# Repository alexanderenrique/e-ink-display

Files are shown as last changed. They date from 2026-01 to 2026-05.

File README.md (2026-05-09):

# E-Ink Display

A custom ESP32-C3-based e-ink display platform with a modular app system, BLE configuration, OTA updates, and three KiCad PCB variants. Built around the Seeed XIAO ESP32-C3 and a 2.9" tri-color (black/white/red) e-ink panel (e.g. GDEM029C90).

## Licensing

Hardware design files in [`e-ink-PCBs/`](e-ink-PCBs/) are licensed under **CERN-OHL-W-2.0**. Firmware, scripts, config examples, and Markdown documentation are under the **MIT License**. See [`LICENSE`](LICENSE), [`LICENSE-HARDWARE`](LICENSE-HARDWARE), and [`LICENSE-SOFTWARE`](LICENSE-SOFTWARE).

## Open source scope (third-party parts)

This project is shared to meet the [Open Source Hardware Definition](https://www.oshwa.org/definition/) and aligns with the spirit of [OSHWA certification requirements](https://certification.oshwa.org/requirements.html) for distinguishing parts outside the licensor’s control.

**Released under the licenses above (our work):**

- Schematics and PCB layouts in [`e-ink-PCBs/`](e-ink-PCBs/) (native KiCad sources and Gerber exports in each variant folder).
- Firmware in [`e-ink_code/firmware/`](e-ink_code/firmware/), plus tooling in [`e-ink_code/scripts/`](e-ink_code/scripts/) and examples under [`e-ink_code/config/`](e-ink_code/config/).

**Not open-sourced by this repository (standard commercial / third-party parts; use vendor documentation):**

| Item | Role | Public datasheet / info |
|---|---|---|
| Seeed XIAO ESP32-C3 | MCU module (ESP32-C3, crystal, antenna, regulators inside module) | Seeed Wiki and [ESP32-C3 technical reference](https://www.espressif.com/en/products/socs/esp32-c3) |
| GDEM029C90 (or compatible Good Display panel) | E-ink panel + timing/controller as supplied by vendor | Vendor PDF (e.g. Good Display product pages) |
| SHT31 | Temperature / humidity sensor IC or module | [Sensirion SHT31 datasheet](https://www.sensirion.com/) |
| FQP27P06, ZXMP4A16G | Discrete MOSFETs | [ON Semi FQP27P06](https://www.onsemi.com/), [Diodes ZXMP4A16G](https://www.diodes.com/) |
| MCP7940N (RTC variant only) | I2C real-time clock | [Microchip MCP7940N](http://ww1.microchip.com/downloads/en/DeviceDoc/20005010F.pdf) |

Optional firmware features (e.g. the **shelf** app) may call HTTP APIs or a companion script (`bin_lookup_server.py`); the hardware and core firmware remain usable without those services.

## Project structure

```
e-ink-display/
├── e-ink-PCBs/                 # KiCad 9 hardware + Gerbers
│   ├── SMD/                    # “SMD” layout variant
│   ├── Throughole-Basic/       # Through-hole, base design
│   ├── Throughole-RTC/         # Through-hole + MCP7940N RTC (+ optional SD header in sch)
│   └── bom/                    # CSV BOM summaries (regenerate from KiCad after edits)
├── e-ink_code/                 # Firmware and scripts (PlatformIO)
│   ├── firmware/               # ESP32-C3 source, core/, apps/, main.cpp
│   ├── scripts/               # OTA, flash, BLE utilities
│   ├── config/examples/       # Device JSON examples
│   ├── platformio.ini
│   └── requirements.txt       # Python deps for helper scripts
├── docs/
│   └── images/                # Add board photos or renders here (recommended for makers)
├── LICENSE, LICENSE-HARDWARE, LICENSE-SOFTWARE, README.md
```

## Hardware

### Components

| Component | Description |
|---|---|
| Seeed XIAO ESP32-C3 | Microcontroller with WiFi and BLE |
| GDEM029C90 | 2.9" 128×296 tri-color e-ink display (black/white/red) |
| SHT31 | I2C temperature and humidity sensor |
| FQP27P06 (and variants may add ZXMP4A16G) | P-channel MOSFETs for power switching |
| 100 µF capacitor | Bulk decoupling (where present in schematic) |
| Resistors | Voltage divider (47 kΩ / 68 kΩ), pull-ups, etc. (see BOM CSVs) |
| Battery connector | LiPo / battery input |
| Through-hole RTC add-ons (Throughole-RTC only) | MCP7940N, 32.768 kHz crystal, load caps; optional SD header in schematic |

### Pin mapping (ESP32-C3)

| Pin | Function |
|-----|---|
| GPIO 3 | SPI SCK (e-ink) |
| GPIO 4 | SPI MOSI (e-ink) |
| GPIO 7 | e-ink CS |
| GPIO 6 | e-ink DC |
| GPIO 5 | e-ink RST |
| GPIO 21 | e-ink BUSY |
| GPIO 9 | I2C SDA (SHT31) |
| GPIO 10 | I2C SCL (SHT31) |
| GPIO 2 | Battery ADC (voltage divider) |
| GPIO 8 | Display + sensor power MOSFET gate |
| GPIO 20 | Battery divider sense enable (`V_SWITCH`) |

### PCB variants

| Directory | Description |
|---|---|
| [`e-ink-PCBs/SMD/`](e-ink-PCBs/SMD/) | Single main FQP27P06 switch; mixed THT footprints on some passives as in schematic |
| [`e-ink-PCBs/Throughole-Basic/`](e-ink-PCBs/Throughole-Basic/) | Through-hole friendly; includes ZXMP4A16G + FQP27P06 in schematic |
| [`e-ink-PCBs/Throughole-RTC/`](e-ink-PCBs/Throughole-RTC/) | Basic topology + MCP7940N RTC, crystal, optional `J6` SD block |

Each folder contains `.kicad_pro`, `.kicad_sch`, `.kicad_pcb`, drill files, and `*.gbr` / `*.gbrjob` fab outputs. **Preferred source for modification is KiCad**, not Gerbers alone.

### Replication: BOM and assembly

1. Open the variant you are building and use **Tools → Generate Bill of Materials** in KiCad to export a fresh CSV when anything changes.
2. Human-readable summaries for each variant live in [`e-ink-PCBs/bom/`](e-ink-PCBs/bom/) — see [`e-ink-PCBs/bom/README.md`](e-ink-PCBs/bom/README.md).
3. Order PCBs using the `e-ink_PCB-job.gbrjob` or individual Gerbers in that variant’s folder.
4. Solder power, MCU module, and display connector before first power-on; double-check battery polarity and MOSFET orientation against the silkscreen.
5. **First firmware:** flash over USB with PlatformIO (see **Build and flash** below) or keep a personal `e-ink_code/FLASH_INSTRUCTIONS.md` locally (that filename is gitignored).
6. **Photos / renders:** add PNGs under [`docs/images/`](docs/images/) (e.g. bare PCB, populated board, enclosure) so others can verify the build.

## Firmware

### Architecture

The firmware uses a plugin-based app system. Core managers handle hardware (WiFi, display, power, OTA, BLE) and are injected into apps via dependency injection. Each app implements the `AppInterface` and is registered with the `AppManager`, which coordinates lifecycle and configuration.

```
Main  -->  AppManager  -->  [Fun | Sensor | Shelf | Messages]
                |
           Core Managers
       (WiFi, Display, Power, OTA, BLE)
```

### Apps

| App | Description |
|-----|---|
| **fun** | Cycles through cat facts, earthquake data, ISS location, useless facts, and local room temperature/humidity. Rotates display mode across deep sleep cycles. |
| **sensor** | Reads temperature and humidity from the SHT31 sensor, displays on screen, and optionally posts data to a Nemo API endpoint. Supports Celsius/Fahrenheit. |
| **shelf** | Queries a bin lookup server to display shelf/bin owner information. Designed for lab inventory labeling. |
| **messages** | Displays a configurable list of up to 10 messages, cycling through them on each wake. |

### BLE configuration

On cold boot (power-on reset), the device advertises via BLE for up to 3 minutes. A BLE central (phone app, script, etc.) can connect and send a JSON configuration including WiFi credentials, app selection, and app-specific settings. The configuration is stored in NVS (non-volatile storage) and persists across deep sleep and reboots.

### Power management

- Battery voltage is read through a 47k/68k resistor divider on GPIO 2.
- Deep sleep is used between display refreshes (configurable per app).
- When battery drops below 5%, the device shows a low-battery message and enters a periodic wake-check sleep (every 5 minutes). Normal operation resumes at 15%.

### OTA updates

The firmware supports HTTPS OTA updates. A deploy script builds the firmware, generates a manifest (version + SHA256), and uploads it to a remote server. Devices check for updates and apply them over WiFi.

### Build environments

Each app has its own PlatformIO build environment that only compiles the code for that specific app:

| Environment | App | Build flag |
|---|-----|---|
| `seeed_xiao_esp32c3` | All apps | (none) |
| `seeed_xiao_fun` | Fun | `-DAPP_FUN` |
| `seeed_xiao_sensor` | Sensor | `-DAPP_SENSOR` |
| `seeed_xiao_shelf` | Shelf | `-DAPP_SHELF` |
| `seeed_xiao_messages` | Messages | `-DAPP_MESSAGES` |

### Dependencies

Managed by PlatformIO (`lib_deps` in `platformio.ini`):

- [GxEPD2](https://github.com/ZinggJM/GxEPD2) — E-ink display driver
- [ArduinoJson](https://github.com/bblanchon/ArduinoJson) ^6.21.3 — JSON parsing
- [Adafruit SHT31 Library](https://github.com/adafruit/Adafruit_SHT31) ^2.2.2 — Temperature/humidity sensor
- [Adafruit Unified Sensor](https://github.com/adafruit/Adafruit_Sensor) ^1.1.9 — Sensor abstraction
- [NimBLE-Arduino](https://github.com/h2zero/NimBLE-Arduino) ^1.4.1 — BLE stack

## Scripts

Located in `e-ink_code/scripts/`:

| Script | Description |
|---|---|
| `deploy_ota.sh` | Build firmware, create manifest, and SCP to OTA server |
| `flash_firmware.sh` | Flash firmware to ESP32-C3 via USB using esptool |
| `bin_lookup_server.py` | Python HTTP server that proxies NEMO API bin/user data for the shelf app |
| `scan_ble.py` | BLE scanner utility to discover and inspect nearby devices |
| `post_build.py` | Copies built firmware binary to `ota/` directory |
| `make_manifest.py` | Generates `manifest.json` with version and SHA256 hash |

## OSHWA certification (administrative next steps)

After this repository reflects the licenses and documentation above, **certification itself is completed on OSHWA’s site**, not in git:

1. Review [Certification requirements](https://certification.oshwa.org/requirements.html) and the [Open Source Hardware checklist](https://www.oshwa.org/resources/open-source-hardware-checklist).
2. Complete the **Certification Mark License Agreement** and submit documentation links for each hardware version you certify.
3. **Register each unique product** that will carry the certification mark, and follow OSHWA’s **mark usage guidelines** (do not imply endorsement by Seeed, Sensirion, Microchip, OSHWA, etc., beyond factual compatibility).
4. Plan for **annual renewal** emails from OSHWA to reaffirm compliance.

Silkscreen and marketing should use only trademarks you are entitled to; third-party logos on the PCB must be cleared separately from this project’s open-license grants.

## Getting started

### Prerequisites

- [PlatformIO](https://platformio.org/) (CLI or IDE plugin)
- [KiCad](https://www.kicad.org/) 9+ (matches current `.kicad_*` schema)
- Python 3 (for utility scripts)

### Build and flash

```bash
cd e-ink_code

# Build a specific app
pio run -e seeed_xiao_sensor

# Upload via USB
pio run -e seeed_xiao_sensor --target upload

# Monitor serial output
pio device monitor
```

### Deploy OTA update

```bash
cd e-ink_code
./scripts/deploy_ota.sh sensor
```

### Run the bin lookup server (shelf app)

```bash
cd e-ink_code
pip install requests python-dotenv
# Set NEMO_API_KEY in a .env file
python scripts/bin_lookup_server.py
```

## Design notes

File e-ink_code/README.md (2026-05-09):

# E-Ink firmware (`e-ink_code`)

PlatformIO firmware for the Seeed **XIAO ESP32-C3** driving a **GDEM029C90-class** 2.9" three-color e-paper display (B/W/R). Pinout and board documentation live in the [repository root README](../README.md).

## Prerequisites

- [PlatformIO](https://platformio.org/) (CLI or IDE)
- Python 3 (OTA helper scripts under `scripts/`)

PlatformIO uses **`src_dir = firmware`** — all application code is under `firmware/`, not `src/`.

## Quick start

```bash
cd e-ink_code

# Build one app (recommended for smaller binaries)
pio run -e seeed_xiao_sensor

pio run -e seeed_xiao_sensor --target upload
pio device monitor
```

## Build environments

| Environment | `APP_*` flag | Typical use |
|---|---|---|
| `seeed_xiao_esp32c3` | *(none — all apps linked)* | Development / multi-app image |
| `seeed_xiao_fun` | `APP_FUN` | Fun / info modules only |
| `seeed_xiao_sensor` | `APP_SENSOR` | Room sensor + optional Nemo |
| `seeed_xiao_shelf` | `APP_SHELF` | Shelf / bin label |
| `seeed_xiao_messages` | `APP_MESSAGES` | Static message list |

Defined in [`platformio.ini`](platformio.ini).

## Source layout

```
e-ink_code/
├── firmware/
│   ├── main.cpp              # Boot, NVS config, app wiring, BLE gating
│   ├── app_manager/          # App selection + JSON configure
│   ├── core/
│   │   ├── hardware_config.h # Pins, battery, OTA URL macros (edit for your server)
│   │   ├── bluetooth/        # Cold-start BLE setup
│   │   ├── display/, wifi/, power/, ota/
│   └── apps/
│       ├── fun/              # Rotating “modules” (sensor + HTTP APIs)
│       ├── sensor/           # SHT31 + optional Nemo posting
│       ├── shelf/            # HTTP client to bin-lookup style server
│       └── messages/         # Up to 10 configured strings
├── scripts/                  # deploy_ota.sh, manifest, flash helpers
├── config/examples/          # JSON shape examples for BLE / tools
├── include/                  # Optional shared headers (e.g. reference CA PEM)
├── partitions.csv
├── version.txt               # Keep in sync with FIRMWARE_VERSION for OTA
└── platformio.ini
```

## Apps (summary)

| App | Role |
|-----|---|
| **fun** | Local SHT31 “room” tile plus optional WiFi feeds (earthquake, cat facts, ISS, trivia); cycles modes; **only this app wires HTTPS OTA** today (`handleOTA()`). |
| **sensor** | Temperature/humidity display; optional Nemo/API posting per `config`. |
| **shelf** | Fetches label text from a configurable HTTP server (`serverHost` / `serverPort` / `binId`). |
| **messages** | Shows a fixed list of lines from config. |

Active app and `config` object come from JSON (BLE-stored NVS or the built-in test default in `main.cpp`). See [`config/examples/README.md`](config/examples/README.md).

## Pins (authoritative: `firmware/core/hardware_config.h`)

| Signal | GPIO |
|---|---|
| SPI SCK | 3 |
| SPI MOSI | 4 |
| E-ink CS | 7 |
| E-ink DC | 6 |
| E-ink RST | 5 |
| E-ink BUSY | 21 |
| I2C SDA / SCL (SHT31) | 9 / 10 |
| Battery ADC | 2 |
| Display + sensor power MOSFET gate | 8 |
| Divider enable `V_SWITCH` | 20 |

## Bluetooth setup (cold start)

- Implemented in [`firmware/core/bluetooth/cold_start_ble.cpp`](firmware/core/bluetooth/cold_start_ble.cpp).
- BLE runs only on a true cold start (not deep-sleep timer wake); advertising window **15 s** (`COLD_START_BLE_WINDOW_SECONDS` in [`cold_start_ble.h`](firmware/core/bluetooth/cold_start_ble.h)).
- WiFi is turned off while BLE is active (ESP32-C3 coexistence).
- After JSON config is written to the TX characteristic, preferences store `configJson` and set a one-shot **`skipBLE`** so the next reboot applies settings without re-entering BLE.

## Power and deep sleep

- Apps call `PowerManager::enterDeepSleep()` after a refresh cycle.
- Set **`DISABLE_DEEP_SLEEP_FOR_TESTING`** to `1` in [`hardware_config.h`](firmware/core/hardware_config.h) to replace deep sleep with a long `delay()` (USB serial stays usable).

## OTA updates

- **Fun** app: `handleOTA()` passes `OTA_VERSION_CHECK_URL`, `ROOT_CA_CERT`, `OTA_PASSWORD`, and `FIRMWARE_VERSION` from [`hardware_config.h`](firmware/core/hardware_config.h) into `OTAManager`.
- Manifest over HTTPS must be JSON with at least **`version`** and **`url`** (firmware `.bin`). Version must be newer than the device (`x.y.z` compared in [`ota_manager.cpp`](firmware/core/ota/ota_manager.cpp)).
- `scripts/make_manifest.py` also writes **`sha256`** for your deployment records; the current firmware path does not verify that hash on device.
- Dual OTA partitions: [`partitions.csv`](partitions.csv). Deploy flow: `scripts/deploy_ota.sh` (see script for host/path variables).

## Scripts

| Script | Purpose |
|---|---|
| `scripts/deploy_ota.sh` | Build, post-build, manifest, SCP to server |
| `scripts/make_manifest.py` | `ota/manifest.json` from `version.txt` + `ota/firmware.bin` |
| `scripts/post_build.py` | Copy firmware binary into `ota/` |
| `scripts/flash_firmware.sh` | USB flash helper |

## Versioning

1. Bump [`version.txt`](version.txt).
2. Match **`FIRMWARE_VERSION`** in [`firmware/core/hardware_config.h`](firmware/core/hardware_config.h).

## License

Firmware, scripts, config examples, and Markdown here are **MIT**. See [`LICENSE-SOFTWARE`](../LICENSE-SOFTWARE) and [`LICENSE`](../LICENSE). Hardware CAD is **CERN-OHL-W-2.0** under [`../e-ink-PCBs/`](../e-ink-PCBs/).

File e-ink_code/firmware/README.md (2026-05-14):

# E-Ink Display Firmware Architecture

This document describes the modular firmware architecture for the ESP32-C3 e-ink display system. The firmware is designed around a plugin-based app system where multiple applications can run on the same hardware, each with its own functionality and configuration.

## Table of Contents

- [Architecture Overview](#architecture-overview)
- [Core Components](#core-components)
- [App System](#app-system)
- [Available Apps](#available-apps)
- [JSON Configuration](#json-configuration)
- [Testing with JSON](#testing-with-json)
- [Adding New Apps](#adding-new-apps)
- [Build and Deployment](#build-and-deployment)

## Architecture Overview

The firmware follows a layered architecture with clear separation of concerns:

```
┌─────────────────────────────────────────┐
│           Main Application              │
│         (main.cpp)                      │
└─────────────────┬───────────────────────┘
                  │
┌─────────────────▼───────────────────────┐
│          App Manager                    │
│    (app_manager/app_manager.*)         │
│  - Manages app lifecycle                │
│  - Handles app switching                │
│  - Parses JSON configuration            │
└─────┬───────────┬───────────┬───────────┘
      │           │           │
┌─────▼─────┐ ┌──▼───┐ ┌─────▼─────┐
│  Fun App  │ │Sensor│ │ Shelf App │
│           │ │ App  │ │           │
└───────────┘ └──────┘ └───────────┘
      │           │           │
      └───────────┴───────────┘
                  │
      ┌───────────┴───────────┐
      │   Core Managers       │
      ├───────────────────────┤
      │  WiFiManager           │
      │  DisplayManager        │
      │  PowerManager          │
      │  OTAManager            │
      └───────────────────────┘
```

### Key Design Principles

1. **Dependency Injection**: Core managers are injected into apps through the `AppInterface`, allowing apps to access hardware and services without tight coupling.

2. **Plugin Architecture**: Apps implement the `AppInterface` and are registered with the `AppManager`. The active app can be switched at runtime or via JSON configuration.

3. **Separation of Concerns**: Each app is self-contained with its own:
   - `app.h/cpp` - Main app logic
   - `fetch.h/cpp` - Data fetching logic
   - `render.h/cpp` - Display rendering logic
   - `config.h` - App-specific configuration

4. **Resource Management**: Apps are responsible for managing their own resources (WiFi connections, display updates, sleep cycles) with guidance from core managers.

## Core Components

### Core Managers

Located in `firmware/core/`, these managers provide hardware abstraction and shared services:

#### WiFiManager (`core/wifi/`)
- Manages WiFi connections
- Handles connection/disconnection lifecycle
- Provides connection status checking

#### DisplayManager (`core/display/`)
- Manages e-ink display initialization and updates
- Provides rendering helpers (text wrapping, battery display)
- Handles SPI initialization and cleanup
- Supports multiple display modes (default, earthquake, ISS data)

#### PowerManager (`core/power/`)
- Battery voltage monitoring and percentage calculation
- Deep sleep management
- Wake-up reason detection
- Power optimization utilities

#### OTAManager (`core/ota/`)
- Over-the-air firmware updates
- Version checking against remote server
- Secure update handling with certificate validation

### Hardware Configuration

All hardware pin definitions and constants are centralized in `firmware/core/hardware_config.h`:

- SPI pins (SCK, MOSI, MISO, CS, DC, RST, BUSY)
- I2C pins (SDA, SCL)
- Power management pins (V_ADC, V_SWITCH)
- Battery voltage divider constants
- WiFi credentials
- OTA server configuration

## App System

### AppInterface

All apps must implement the `AppInterface` base class (`app_manager/app_interface.h`):

```cpp
class AppInterface {
public:
    virtual bool begin() = 0;              // Initialize app
    virtual void loop() = 0;               // Main app loop
    virtual void end() = 0;                // Cleanup on app switch
    virtual const char* getName() = 0;     // Return app name
    virtual bool configure(const JsonObject& config); // Optional config
    
    // Dependencies (injected by AppManager)
    void setWiFiManager(WiFiManager* wifi);
    void setDisplayManager(DisplayManager* display);
    void setPowerManager(PowerManager* power);
    void setOTAManager(OTAManager* ota);
};
```

### AppManager

The `AppManager` (`app_manager/app_manager.*`) coordinates the app system:

**Key Responsibilities:**
- Register apps with unique names
- Set active app (by name or index)
- Parse JSON configuration and apply it
- Inject core manager dependencies into apps
- Manage app lifecycle (begin/loop/end)
- Provide app query methods

**Key Methods:**
- `registerApp(AppInterface* app, const char* name)` - Register an app
- `setActiveApp(const char* name)` - Switch to an app by name
- `configureFromJson(const char* jsonString)` - Configure from JSON
- `begin()` - Start the active app
- `loop()` - Run the active app's loop

## Available Apps

### Fun App (`apps/fun/`)

Displays rotating content including:
- Room temperature and humidity (from SHT31 sensor, no WiFi needed)
- Earthquake data (requires WiFi)
- Cat facts (requires WiFi)
- ISS location data (requires WiFi)
- Useless facts (requires WiFi)
- Optional one-off slides pushed from the aggregator (**special messages**; requires WiFi, device UUID, and server-side queue — see **`apis.special_messages`** below)

**Display Modes:** Cycles through 5 modes (0-4), persisting across deep sleep using `RTC_DATA_ATTR`.

**WiFi / aggregator usage:** The ESP only calls the fun HTTP endpoints for modes that are enabled in configuration (see **`config.apis`** below). The server does not enforce per-mode policy; it responds to whatever the client requests once `X-Fun-Key` matches (if the server is configured with `FUN_API_KEY`).

### Fun app `apis` flags (BLE / stored JSON)

When the fun app is configured (including data loaded from NVS after provisioning over BLE), optional `config.apis` booleans turn each **display mode** on or off:

| Key | Mode | Content |
|-----|---|---|
| `room_data` | 0 | Room temp/humidity (and WiFi RSSI when connected) |
| `earthquake` | 1 | Earthquake slide (WiFi) |
| `cat_facts` | 2 | Cat facts — one `GET /v1/fun/screen?m=2` per wake (WiFi), unless `all_new_facts` |
| `iss` | 3 | ISS slide (WiFi) |
| `useless_facts` | 4 | Useless facts — one `GET /v1/fun/screen?m=4` per wake (WiFi); ignored when `all_new_facts` is on |
| `all_new_facts` | (uses mode 2) | When `true`, mode 2 calls `GET /v1/fun/facts/mixed?count=1` so the device shows a random slide from **any** non-empty `data/*_facts.json` pool on the server; mode 4 is skipped so cat vs useless toggles do not duplicate a second facts slot |
| `special_messages` | (WiFi modes 1–4) | When `true` (default), each wake in an online WiFi mode first calls `GET /v1/fun/special` using the stored device UUID (`X-Device-Id`). If the server returns a slide, that slide is shown **instead of** the normal earthquake/cat/ISS/mixed/useless slide for this cycle (the message is dequeued server-side). If the server responds with no body (`204`), the firmware continues with the usual mode fetch |

Fact text is always fetched live over WiFi for those modes (no NVS queue). The server still exposes `GET /v1/fun/facts/batch` for other clients; the fun app firmware no longer uses it.

**Defaults:** If there is no `apis` object (e.g. `{"app":"fun","config":{}}` in [`main.cpp`](main.cpp) when nothing is stored from BLE), **all flags default to on** in [`apps/fun/app.h`](apps/fun/app.h). To limit network use, set `apis` explicitly, for example:

```json
{
  "app": "fun",
  "config": {
    "refreshInterval": 2,
    "apis": {
      "room_data": true,
      "cat_facts": true,
      "iss": true,
      "earthquake": false,
      "useless_facts": false,
      "all_new_facts": false,
      "special_messages": true
    }
  }
}
```

BLE provisioning stores a top-level `apis` object that [`main.cpp`](main.cpp) merges into `config` when building the app-manager JSON.

**Device identity (aggregator / special messages):** In top-level provisioning JSON you can send a human-readable label (any of `displayName`, `deviceFriendlyName`, or `friendly_name`) which is persisted as `deviceFriendlyName` in Preferences and sent on each aggregator request as the `X-Device-Name` header. Optionally include `deviceId` / `device_id` (UUID) if you mint the ID in the provisioning app (**phone-mint**); otherwise NVS keeps `deviceId` empty until the firmware calls `POST /v1/devices/register` once (server-mint UUID), then repeats that id as `X-Device-Id` on later calls. To queue a one-off slide for a given UUID (or a named group), use the server admin API documented in [server README — Special messages](../server/README.md#special-messages-targeted-slides).

**Special messages — did the server / device accept it?**

- **Enqueue accepted (admin):** A successful `POST /v1/admin/special` returns HTTP **200** with JSON like `{"ok":true,"enqueued_for":["…uuid…"],"unknown_groups":[]}` — **`enqueued_for`** is the definitive list of device UUIDs that received a queued copy. If **`ok`** is **`false`**, read **`error`**; **`unknown_groups`** means one or more **`group_ids`** were not defined in the on-disk store yet (define them with **`groups`** in the same request, or persist them beforehand — see below).
- **Still waiting vs. consumed (device):** There is **no separate HTTP endpoint** for delivery receipts. Pending items live in the server file **`FUN_SPECIAL_STORE`** (default `data/special_messages.json`; often **`/var/lib/fun-aggregator/special_messages.json`** on a Pi — see server README). It is structured as **`queues`** (per-device UUID FIFO arrays) and **`groups`** (named lists of UUIDs). After enqueue, **`queues.<device-uuid>`** holds pending slide objects until the firmware’s next successful **`GET /v1/fun/special`**; that POP **removes** the head entry and returns the slide, so seeing the slide on the ink display is the strongest proof the device consumed it. Inspect the JSON on the Pi (or `jq '.queues."YOUR-DEVICE-UUID"' /path/to/special_messages.json`) to see what is **still queued**; **`204`** on **`/v1/fun/special`** means nothing left for that UUID. Firmware serial output logs HTTP/JSON failures for **`/v1/fun/special`** (see `[FunFetch] Special slide …`); a clean fetch does not spam success logs — use the screen or the store file.

**Special messages — grouping UUIDs**

Named groups are **server-side strings** pointing at **lists of device UUID strings** in **`FUN_SPECIAL_STORE.groups`**. Typical workflow from your laptop against the public API (same pattern on the Pi with `http://127.0.0.1:8081`):

1. **Define or update a group** and **enqueue in one request** — the **`groups`** object is merged **before** **`group_ids`** is resolved for that POST:

```bash
curl -sS -X POST 'https://YOUR-HOST/v1/admin/special' \
  -H 'Content-Type: application/json' \
  -H 'X-Fun-Admin-Key: YOUR_ADMIN_SECRET' \
  -d '{"text":"Hi everyone","group_ids":["book_club"],"groups":{"book_club":["uuid-1-here","uuid-2-here"]}}'
```

2. **Later posts** can reference **`group_ids":["book_club"]`** alone if that group already exists in the JSON file — or supply **`groups`** again to replace the membership (the server **replaces** the list for that name when **`groups`** is present; an **empty array** **`"groups":{"book_club":[]}`** **removes** that group mapping).

You can combine **`device_ids`** and **`group_ids`** in the same body; duplicates are merged. Full curl examples and env vars (**`FUN_ADMIN_API_KEY`**, **`FUN_SPECIAL_STORE`**) are in [server README — Special messages](../server/README.md#special-messages-targeted-slides).

**Dependencies:** SHT31 sensor (I2C), WiFi for API calls

### Sensor App (`apps/sensor/`)

Dedicated sensor reading and display app.

**Status:** Implementation in progress

### Shelf App (`apps/shelf/`)

Shelf/bookshelf display app.

**Status:** Implementation in progress

## JSON Configuration

The firmware supports configuration via JSON strings. This allows for:
- Runtime app selection
- App-specific configuration
- Testing different configurations without recompiling
- Future remote configuration support

### JSON Format

The JSON configuration follows this structure:

```json
{
  "app": "app_name",
  "config": {
    // App-specific configuration (optional)
  }
}
```

**Required Fields:**
- `app` (string): The name of the app to activate. Must match a registered app name.

**Optional Fields:**
- `config` (object): App-specific configuration object. Each app can define its own configuration schema.

### JSON Parsing

The `AppManager::configureFromJson()` method:
1. Parses the JSON string using ArduinoJson
2. Validates the `app` field exists
3. Finds the registered app matching the name
4. Switches to that app (calling `end()` on the previous app if switching)
5. Calls the app's `configure()` method with the `config` object (if provided)
6. Returns `true` on success, `false` on failure

**Error Handling:**
- Invalid JSON: Returns `false`, logs parse error
- Missing `app` field: Returns `false`, logs error
- Unknown app name: Returns `false`, logs error
- Configuration failure: Returns `false` if app's `configure()` returns `false`

## Testing with JSON

### Method 1: Hardcoded Test Configuration

Edit `firmware/main.cpp` and modify the `TEST_CONFIG_JSON` constant:

```cpp
// Example: Switch to sensor app
const char* TEST_CONFIG_JSON = 
    "{\"app\": \"sensor\", \"config\": {}}";

// Example: Switch to shelf app
const char* TEST_CONFIG_JSON = 
    "{\"app\": \"shelf\", \"config\": {}}";

// Example: Fun app with empty config (default)
const char* TEST_CONFIG_JSON = 
    "{\"app\": \"fun\", \"config\": {}}";
```

The configuration is applied in `setup()`:

```cpp
if (appManager.configureFromJson(TEST_CONFIG_JSON)) {
    Serial.println("[Main] Configuration loaded successfully");
} else {
    Serial.println("[Main] Configuration failed, using default");
    appManager.setActiveApp("fun"); // Fallback
}
```

### Method 2: Serial Input (Future Enhancement)

For runtime configuration, you could add Serial input parsing:

```cpp
void loop() {
    if (Serial.available()) {
        String jsonInput = Serial.readString();
        if (appManager.configureFromJson(jsonInput.c_str())) {
            Serial.println("Configuration updated!");
            appManager.begin(); // Restart with new config
        }
    }
    appManager.loop();
}
```

### JSON Examples

#### Basic App Selection

```json
{
  "app": "fun"
}
```

#### App Selection with Empty Config

```json
{
  "app": "sensor",
  "config": {}
}
```

#### App Selection with Configuration (Example)

```json
{
  "app": "fun",
  "config": {
    "displayMode": 2,
    "updateInterval": 300,
    "enableWiFi": true
  }
}
```

**Note:** The actual configuration schema depends on each app's `configure()` implementation. Currently, most apps use the default `configure()` which accepts any config and returns `true`.

### Testing Workflow

1. **Edit Configuration**: Modify `TEST_CONFIG_JSON` in `main.cpp`
2. **Build**: Compile the firmware with PlatformIO
3. **Upload**: Flash to device
4. **Monitor**: Check Serial output for configuration status
5. **Verify**: Confirm the correct app is running

### Serial Output

When configuration is applied, you'll see:

```
[AppManager] Registered app: fun
[AppManager] Registered app: sensor
[AppManager] Registered app: shelf
[AppManager] Setting active app to: fun
[AppManager] App configured successfully
[Main] Configuration loaded successfully
[FunApp] Starting Fun App
```

If configuration fails:

```
[AppManager] JSON parse error: InvalidInput
[Main] Configuration failed, using default
[AppManager] Switched to app: fun
```

## Adding New Apps

To add a new app to the system:

### 1. Create App Directory Structure

```
firmware/apps/your_app/
├── app.h
├── app.cpp
├── config.h
├── fetch.h      (optional, for data fetching)
├── fetch.cpp    (optional)
├── render.h     (optional, for display rendering)
└── render.cpp   (optional)
```

### 2. Implement AppInterface

Create your app class inheriting from `AppInterface`:

```cpp
// apps/your_app/app.h
#include "../../app_manager/app_interface.h"

class YourApp : public AppInterface {
public:
    YourApp();
    virtual ~YourApp() {}
    
    bool begin() override;
    void loop() override;
    void end() override;
    const char* getName() override { return "your_app"; }
    
    // Optional: Override configure if you need JSON config
    bool configure(const JsonObject& config) override;
    
private:
    // Your app-specific members
};
```

### 3. Implement Required Methods

```cpp
// apps/your_app/app.cpp
#include "app.h"

bool YourApp::begin() {
    Serial.println("[YourApp] Starting");
    if (_display) {
        _display->begin();
    }
    return true;
}

void YourApp::loop() {
    // Your app logic here
    // Access managers via _wifi, _display, _power, _ota
}

void YourApp::end() {
    Serial.println("[YourApp] Ending");
    // Cleanup resources
}

bool YourApp::configure(const JsonObject& config) {
    // Parse config if needed
    // Return true on success, false on failure
    return true;
}
```

### 4. Register App in main.cpp

```cpp
// Add include
#include "apps/your_app/app.h"

// Create instance
YourApp yourApp;

// Register in setup()
appManager.registerApp(&yourApp, "your_app");
```

### 5. Add JSON Configuration Support (Optional)

If your app needs configuration, implement `configure()`:

```cpp
bool YourApp::configure(const JsonObject& config) {
    if (config.containsKey("someSetting")) {
        _someSetting = config["someSetting"];
    }
    return true;
}
```

Then users can configure it:

```json
{
  "app": "your_app",
  "config": {
    "someSetting": 123
  }
}
```

## Build and Deployment

### Prerequisites

- PlatformIO installed
- ESP32-C3 board support
- Required libraries (see `platformio.ini`)

### Build

```bash
pio run
```

### Upload

```bash
pio run --target upload
```

### Monitor Serial Output

```bash
pio device monitor
```

### OTA Updates

The firmware supports OTA updates via `OTAManager`. Configure:
- `OTA_VERSION_CHECK_URL` in `hardware_config.h`
- `OTA_PASSWORD` in `hardware_config.h`
- `ROOT_CA_CERT` in `hardware_config.h`

Apps can check for updates during their loop:

```cpp
if (_ota && _wifi && _wifi->isConnected()) {
    _ota->handle();
    if (_ota->checkForUpdate()) {
        _ota->performUpdate();
    }
}
```

## File Structure

```
firmware/
├── main.cpp                    # Entry point, app registration
├── core/                       # Core managers
│   ├── hardware_config.h      # Hardware pin definitions
│   ├── wifi/                  # WiFi management
│   ├── display/               # Display management
│   ├── power/                 # Power management
│   └── ota/                   # OTA updates
├── app_manager/               # App system
│   ├── app_interface.h        # Base app interface
│   ├── app_manager.h          # App manager header
│   └── app_manager.cpp        # App manager implementation
└── apps/                      # Application plugins
    ├── fun/                   # Fun app
    ├── sensor/                # Sensor app
    └── shelf/                 # Shelf app
```

## Troubleshooting

### App Not Found Error

- Ensure the app is registered in `main.cpp` with `registerApp()`
- Check that the app name in JSON matches the registration name (case-sensitive)
- Verify the app's `getName()` returns the expected string

### Configuration Not Applied

- Check Serial output for JSON parse errors
- Verify JSON syntax is valid (use a JSON validator)
- Ensure the app's `configure()` method returns `true`
- Check that `config` field is a JSON object, not a string

### App Not Starting

- Verify `begin()` returns `true`
- Check Serial output for initialization errors
- Ensure core managers are properly initialized before app registration
- Verify hardware connections match `hardware_config.h`

## Future Enhancements

Potential improvements to the architecture:

1. **Remote Configuration**: Load JSON config from a web server or MQTT broker
2. **App State Persistence**: Save app state to EEPROM/Flash
3. **Dynamic App Loading**: Load apps from SPIFFS or external storage
4. **Configuration Schema Validation**: Validate JSON against app-defined schemas
5. **App Dependencies**: Support for apps that depend on other apps
6. **Multi-App Mode**: Run multiple apps simultaneously (split screen, cycling)

## License

Firmware in this directory is licensed under the MIT License. See
[`LICENSE-SOFTWARE`](../../LICENSE-SOFTWARE) and the overview in
[`LICENSE`](../../LICENSE).

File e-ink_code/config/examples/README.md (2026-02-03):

# Device config JSON examples

Deploy these (or your variants) to `https://ota.denton.works/config/devices/` so each device can fetch `{name}.json` (e.g. `dillon.json`) or fall back to `default.json`.

All keys are **optional**; firmware uses defaults when a key is missing.

| Key | Type | Default | Description |
|-----|---|---|---|
| `refresh_ms` | number | 300000 | Milliseconds between display cycles (min 10000). |
| `modules` | object | all true | Human-readable toggles. Each key is a module name, value is `true`/`false`. Names: `room`, `meow_fact`, `Earthquakes`, `Iss_location`, `useless_fact`. Cycle order: room → Earthquakes → meow_fact → Iss_location → useless_fact. |
| `messages_url` | string | "" | URL for custom messages endpoint. |
| `messages_key` | string | "" | Optional API key for messages. |
| `key` | string | "" | Arbitrary per-device value. |

To add new config options later: extend the schema in `src_hold/device_config.h`, parse in `device_config.cpp`, and add a getter with a default.

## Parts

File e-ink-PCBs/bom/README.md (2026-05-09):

# Bill of materials

CSV summaries here mirror the KiCad schematics in each PCB variant. **Regenerate
from KiCad** when you change symbols or values so MPNs and references stay
accurate:

1. Open `e-ink_PCB.kicad_sch` in KiCad for the variant you care about.
2. **Tools → Generate Bill of Materials** (pick fields you want, e.g.
   Reference, Value, Footprint, MPN).
3. Export CSV and replace or supplement the files in this directory.

These CSVs intentionally omit power symbols (`#PWR*`) and decorative
schematic-only items.

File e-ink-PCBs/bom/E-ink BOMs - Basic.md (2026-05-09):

# Basic display BOM (no RTC)

| Reference | Value | Suggested MPN / part | Description | Footprint notes | Qty | US$ @ 1 ea | US$ line @ 1 | US$ @ 10 ea | US$ line @ 10 | US$ @ 100 ea | US$ line @ 100 | Notes | Link |
| --- | --- | --- | --- | --- | ---:| ---:| ---:| ---:| ---:| ---:| ---:| --- | --- |
| J2 | e-ink display |  |  |  | 1 | $9.00000 | $9.00000 | $8.00000 | $8.00000 | $8.00000 | $8.00000 | Hard to find the exact one | [AliExpress][j2-link] |
| J1 | Seeed-ESP32 C3 |  | MCU |  | 1 | $4.90000 | $4.90000 | $4.20000 | $4.20000 | $4.20000 | $4.20000 |  |  |
| ANT1 | u.fl Antenna |  | Wifi Antenna |  | 1 | $0.50000 | $0.50000 | $0.50000 | $0.50000 | $0.50000 | $0.50000 |  |  |
| J3 | SHT31 | SHT-31D |  |  | 1 | $2.30000 | $2.30000 | $1.50000 | $1.50000 | $1.00000 | $1.00000 | Many kind of SHT sensors, using SHT-31D, easy to find on amazon |  |
| 47k1 | 47 kΩ | MFR50SFTE52-47K | Throughole, 0.5W, metal film |  | 1 | $0.10000 | $0.10000 | $0.04800 | $0.04800 | $0.03070 | $0.03070 | Top of Voltage Divider |  |
| 68k1 | 68 kΩ | MF0207FTE52-68K | Throughole, 0.5W, metal film |  | 1 | $0.10000 | $0.10000 | $0.05000 | $0.05000 | $0.03280 | $0.03280 | Bottom of Voltage divider |  |
| 1M1 | 1 MΩ | MFR-25FTE52-1M | Throughole, 0.5W, metal film |  | 1 | $0.10000 | $0.10000 | $0.03700 | $0.03700 | $0.02400 | $0.02400 | Pull up for MOSFET; placement 1 of 2 from original qty-2 line. |  |
| 1M2 | 1 MΩ | MFR-25FTE52-1M | Throughole, 0.5W, metal film |  | 1 | $0.10000 | $0.10000 | $0.03700 | $0.03700 | $0.02400 | $0.02400 | Pull up for MOSFET; placement 2 of 2 from original qty-2 line. |  |
| Q1 | P-Type MOSFET | BSP92PH6327XTSA1 | SMD, SOT-223-4 |  | 1 | $0.93000 | $0.93000 | $0.58000 | $0.58000 | $0.37000 | $0.37000 | P-Channel 250 V 260mA (Ta) 1.8W (Ta) Surface Mount PG-SOT223-4; placement 1 of 2 from original qty-2 BOM line. |  |
| Q2 | P-Type MOSFET | BSP92PH6327XTSA1 | SMD, SOT-223-4 |  | 1 | $0.93000 | $0.93000 | $0.58000 | $0.58000 | $0.37000 | $0.37000 | P-Channel 250 V 260mA (Ta) 1.8W (Ta) Surface Mount PG-SOT223-4; placement 2 of 2 from original qty-2 BOM line. |  |
| C1 | 10 µF | FG18X5R1E106MRT06 |  |  | 1 | $0.04500 | $0.04500 | $0.27300 | $0.27300 | $0.18190 | $0.18190 | Power Entry Cap |  |
| C2 | 0.1 µF | K104K15X7RF5TL2 | Throughole, Ceramic |  | 1 | $0.26000 | $0.26000 | $0.14900 | $0.14900 | $0.09480 | $0.09480 | One for each power pin; placement 1 of 2 from original qty-2 line. |  |
| C3 | 0.1 µF | K104K15X7RF5TL2 | Throughole, Ceramic |  | 1 | $0.26000 | $0.26000 | $0.14900 | $0.14900 | $0.09480 | $0.09480 | One for each power pin; placement 2 of 2 from original qty-2 line. |  |
| C4 | 10 pF | K100J15C0GF53L2 | Throughole, Ceramic |  | 1 | $0.24000 | $0.24000 | $0.14000 | $0.14000 | $0.08900 | $0.08900 | For oscillator; placement 1 of 2 from original qty-2 line. |  |
| C5 | 10 pF | K100J15C0GF53L2 | Throughole, Ceramic |  | 1 | $0.24000 | $0.24000 | $0.14000 | $0.14000 | $0.08900 | $0.08900 | For oscillator; placement 2 of 2 from original qty-2 line. |  |
| TOTALS |  |  | BOM cost rollup (all lines summed at each price breakpoint) |  |  |  | **$20.00500** |  | **$16.38300** |  | **$15.10100** | Carried forward from original CSV columns Cost/single/unit ($20.005), Cost/10/unit ($16.383), cost/100/unit ($15.101). |  |

## Rolled-up BOM cost (from sheet)

| Breakpoint | Total (all lines) |
| --- | ---: |
| Buy as ones (matches `Cost_Single_line_total` sum) | $20.00500 |
| Buy at 10-unit pricing | $16.38300 |
| Buy at 100-unit pricing | $15.10100 |

[j2-link]: https://www.aliexpress.us/item/3256808057925649.html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

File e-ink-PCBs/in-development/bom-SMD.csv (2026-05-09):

Reference | Value | Suggested_MPN_or_part | Description | Footprint_notes
J1 | SEED C3 | Seeed Studio XIAO ESP32-C3 | ESP32-C3 module Wi-Fi/BLE | Use official XIAO ESP32-C3; match project footprint Module:XIAO-ESP32C3-SMD_alex
J2 | e-ink-display | GDEM029C90 (or vendor equivalent) | 2.9in 128x296 B/W/R e-paper + flex tail | Install per panel vendor drawing; aligns to 8p 2.54mm header on PCB
J3 | SHT31 | Adafruit 2857 / Sensirion SHT31 breakout or bare IC | Temperature & humidity I2C sensor | Symbol is 4-pin 2.54mm socket
J4 | 100 uF CAP |  | Electrolytic bulk decoupling near supply | Radial 8mm pitch per schematic; verify voltage rating for your battery max
J5 | Batt Conn |  | 2-pin LiPo / battery input | 2.00mm pitch 1x2 socket per footprint
C1 | C_Small_US |  | Ceramic decoupling (populate value per your design—e.g. 100nF) | Disc cap footprint in schematic
R1 | R_Small_US | 47 kΩ ±5% 1/4W | Battery divider top (to GPIO ADC) | Match firmware divider math in software docs
R2 | R_Small_US | 68 kΩ ±5% 1/4W | Battery divider bottom | Pair with R1 for expected ratio
R3 | R_Small_US |  | Pull-up / bias (set value per schematic trace—verify in KiCad) | Axial THT in schematic
Q1 | FQP27P06 | ON Semi FQP27P06 | P-channel power switch | Schematic shows TO-220 footprint; confirm against PCB copper

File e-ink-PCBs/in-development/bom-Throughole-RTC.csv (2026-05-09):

Reference | Value | Suggested_MPN_or_part | Description | Footprint_notes
J1 | SEED C3 | Seeed Studio XIAO ESP32-C3 | ESP32-C3 module | Through-hole XIAO footprint variant
J2 | e-ink-display | GDEM029C90 (or vendor equivalent) | E-paper panel | 8p 2.54mm header
J3 | SHT31 | Adafruit 2857 / SHT31 | I2C sensor | 1x4 2.54mm socket
C2 | C_Small_US |  | RTC crystal load / bypass (value per crystal datasheet)
C3 | C_Small_US |  | RTC crystal load / bypass (value per crystal datasheet)
BT1 | Battery_Cell |  | RTC backup cell (symbolic) | Use non-rechargeable cell appropriate for MCP7940N VBAT per datasheet
R3 | R_Small_US |  | Pull-up or bias (confirm value in schematic)
Q1 | FQP27P06 | ON Semi FQP27P06 | P-channel MOSFET power switch
Q2 | ZXMP4A16G | Diodes Inc. ZXMP4A16G | P-channel MOSFET SOT-223
TOP_47K | R_Small_US | 47 kΩ | Battery divider top
BTTM_68K | R_Small_US | 68 kΩ | Battery divider bottom

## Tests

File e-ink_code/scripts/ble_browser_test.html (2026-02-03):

# BLE Browser Test (E-Ink Display)

Uses Web Bluetooth to find and connect to your ESP32. Works in Chrome and Edge (HTTPS or localhost).

Scan & connect to E-Ink Display Disconnect

Idle. Click “Scan & connect” and choose “E-Ink Display” in the picker.

Ensure the display is on and in the 60s BLE window after a cold start. Only one tab should use the device at a time.

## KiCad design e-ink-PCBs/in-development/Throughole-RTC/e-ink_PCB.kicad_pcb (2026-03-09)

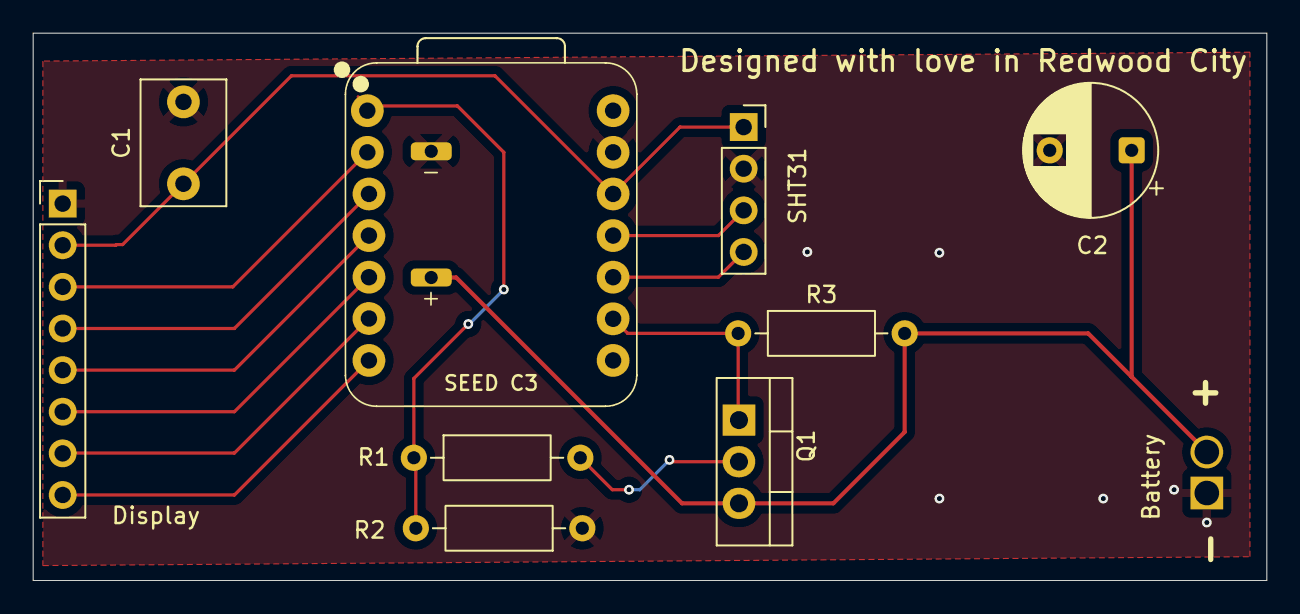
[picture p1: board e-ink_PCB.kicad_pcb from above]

Board: 2 copper layers, 75.3 x 33.4 mm, 10 parts (0 on the bottom side), 14 nets.

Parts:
C1: C_Small_US; C_Disc_D7.5mm_W5.0mm_P5.00mm
J1: SEED C3; XIAO-ESP32C3-Throughole_alex
J2: e-ink-display; PinHeader_1x08_P2.54mm_Vertical
J3: SHT31; PinSocket_1x04_P2.54mm_Vertical
J4: C2; CP_Radial_D8.0mm_P5.00mm
J5: Battery; PinSocket_1x02_P2.00mm_Vertical
Q1: FQP27P06; TO-220-3_Vertical
R1, R2, R3: R_Small_US; R_Axial_DIN0207_L6.3mm_D2.5mm_P10.16mm_Horizontal

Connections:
GND: C1.1, J1.BAT- (Pin_1), J1.GND (Pin_2), J2.GND (Pin_1), J3.GND (Pin_2), J4.- (Pin_1), J5.1, R2.1
unnamed: J1.2 (Pin_8), R1.1, R2.2
unnamed: C1.2, J1.3.3V (Pin_3), J2.VCC (Pin_2), J3.VIN (Pin_1)
unnamed: J1.3 (Pin_7), J2.SCL (Pin_3)
unnamed: J1.4 (Pin_6), J2.SDA (Pin_4)
unnamed: J1.5, J2.RES (Pin_5)
unnamed: J1.6 (Pin_4), J2.DC (Pin_6)
unnamed: J1.7 (Pin_3), J2.CS (Pin_7)
unnamed: J1.21 (Pin_2), J2.BUSY (Pin_8)
unnamed: J1.10 (Pin_4), J3.SCL (Pin_3)
unnamed: J1.9 (Pin_5), J3.SDA (Pin_4)
unnamed: J1.BAT+ (Pin_1), J4.+ (Pin_2), J5.2, Q1.3 (S), R3.2
unnamed: Q1.2 (D), R1.2
unnamed: J1.8 (Pin_6), Q1.1 (G), R3.1

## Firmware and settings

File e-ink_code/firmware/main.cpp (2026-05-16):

#include <Arduino.h>
#include "core/wifi/wifi_manager.h"
#include "core/display/display_manager.h"
#include "core/power/power_manager.h"
#include "core/ota/ota_manager.h"
#include "core/bluetooth/cold_start_ble.h"
#include "app_manager/app_manager.h"
#include <ArduinoJson.h>
// Include only selected apps (or all if no APP_* flags, for default env)
#if defined(APP_FUN)
#include "apps/fun/app.h"
#endif
#if defined(APP_SENSOR)
#include "apps/sensor/app.h"
#endif
#if defined(APP_SHELF)
#include "apps/shelf/app.h"
#endif
#if defined(APP_MESSAGES)
#include "apps/messages/app.h"
#endif
#if !defined(APP_FUN) && !defined(APP_SENSOR) && !defined(APP_SHELF) && !defined(APP_MESSAGES)
#include "apps/fun/app.h"
#include "apps/sensor/app.h"
#include "apps/shelf/app.h"
#include "apps/messages/app.h"
#endif
#include "esp_sleep.h"
#include "esp_system.h"
#include "hardware_config.h"

// Core managers
WiFiManager wifiManager;
DisplayManager displayManager;
PowerManager powerManager;
OTAManager otaManager;
ColdStartBle coldStartBle;

// App manager
AppManager appManager;

// App instances (only linked when their app is enabled)
#if defined(APP_FUN)
FunApp funApp;
#endif
#if defined(APP_SENSOR)
SensorApp sensorApp;
#endif
#if defined(APP_SHELF)
ShelfApp shelfApp;
#endif
#if defined(APP_MESSAGES)
MessagesApp messagesApp;
#endif
#if !defined(APP_FUN) && !defined(APP_SENSOR) && !defined(APP_SHELF) && !defined(APP_MESSAGES)
FunApp funApp;
SensorApp sensorApp;
ShelfApp shelfApp;
MessagesApp messagesApp;
#endif

// Default app name for this build (first available)
#if defined(APP_FUN) && !defined(APP_SENSOR) && !defined(APP_SHELF)
#define DEFAULT_APP_NAME "fun"
#elif defined(APP_SENSOR)
#define DEFAULT_APP_NAME "sensor"
#elif defined(APP_SHELF)
#define DEFAULT_APP_NAME "shelf"
#elif defined(APP_MESSAGES)
#define DEFAULT_APP_NAME "messages"
#else
#define DEFAULT_APP_NAME "fun"  // all apps or fallback
#endif

// Dummy JSON configuration for testing
// Format: {"app": "app_name", "config": {...}}
const char* TEST_CONFIG_JSON =
    "{\"app\": \"" DEFAULT_APP_NAME "\", \"config\": {}}";

void setup() {
    Serial.begin(115200);
    
    // Ensure display + sensor rail is OFF immediately on boot.
    // With an added MOSFET, leaving the gate floating can cause inrush/brownouts
    // that prevent BLE from reliably starting on initial power-up.
    pinMode(POWER_DISPLAY_SENSOR_PIN, OUTPUT);
    digitalWrite(POWER_DISPLAY_SENSOR_PIN, HIGH); // HIGH = power off (see hardware_config.h)

    uint32_t bootStartMs = millis();
    delay(1000);
    
    // Print wake reason
    esp_sleep_wakeup_cause_t wakeup_reason = powerManager.getWakeupCause();
    esp_reset_reason_t reset_reason = esp_reset_reason();
    Serial.println();
    Serial.println("========== BOOT ==========");
    Serial.print("[Main] millis: ");
    Serial.println(millis());
    switch(wakeup_reason) {
        case ESP_SLEEP_WAKEUP_EXT0: Serial.println("Wakeup caused by external signal using RTC_IO"); break;
        case ESP_SLEEP_WAKEUP_EXT1: Serial.println("Wakeup caused by external signal using RTC_CNTL"); break;
        case ESP_SLEEP_WAKEUP_TIMER: Serial.println("Wakeup caused by timer"); break;
        case ESP_SLEEP_WAKEUP_TOUCHPAD: Serial.println("Wakeup caused by touchpad"); break;
        case ESP_SLEEP_WAKEUP_ULP: Serial.println("Wakeup caused by ULP program"); break;
        default: Serial.println("Wakeup was not caused by deep sleep"); break;
    }
    Serial.print("[Main] Reset reason: ");
    Serial.println((int)reset_reason);
    Serial.print("[Main] Free heap: ");
    Serial.println(ESP.getFreeHeap());
    Serial.print("[Main] Display rail pin (");
    Serial.print(POWER_DISPLAY_SENSOR_PIN);
    Serial.print(") state: ");
    Serial.println(digitalRead(POWER_DISPLAY_SENSOR_PIN));

    // Check battery level on wakeup
    // If we woke from timer (likely from low battery sleep), check if battery has recovered
    int batteryPercent = powerManager.getBatteryPercentage();
    float batteryVoltage = powerManager.getBatteryVoltage();
    Serial.print("[Main] Battery level: ");
    Serial.print(batteryPercent);
    Serial.println("%");
    Serial.print("[Main] Battery voltage: ");
    Serial.println(batteryVoltage, 3);
    
    if (wakeup_reason == ESP_SLEEP_WAKEUP_TIMER) {
        // We woke from timer - could be from low battery sleep or normal sleep
        // Check if battery is still low
        if (batteryPercent < BATTERY_RESUME_THRESHOLD_PERCENT) {
            Serial.println("[Main] Battery still low, showing message and entering low battery sleep");
            displayManager.begin();
            displayManager.displayLowBatteryMessage();
            delay(2000); // Give time for message to be visible
            powerManager.enterLowBatterySleep();
            // Code never reaches here
            return;
        } else {
            Serial.println("[Main] Battery recovered, resuming normal operation");
        }
    }
    
    // Check if battery is critically low (before starting normal operation)
    if (batteryPercent <= BATTERY_LOW_THRESHOLD_PERCENT) {
        Serial.println("[Main] Battery critically low, showing message and entering low battery sleep");
        displayManager.begin();
        displayManager.displayLowBatteryMessage();
        delay(2000); // Give time for message to be visible
        powerManager.enterLowBatterySleep();
        // Code never reaches here
        return;
    }

    // Decide whether we will run BLE on this boot, and consume skipBLE flag once.
    bool skipBle = ColdStartBle::shouldSkipBle();
    bool willRunBle = (!skipBle && reset_reason != ESP_RST_DEEPSLEEP);
    Serial.print("[Main] willRunBle: ");
    Serial.println(willRunBle ? "TRUE" : "FALSE");

    // Per your request: show the Bluetooth config screen first, wait ~10s, then start BLE.
    if (willRunBle) {
        Serial.print("[Main] Showing BLE screen at ms=");
        Serial.println(millis());
        displayManager.begin();
        displayManager.displayBluetoothConfigMode(DEFAULT_APP_NAME);
        displayManager.disableSPI();
        Serial.print("[Main] BLE screen done, SPI disabled at ms=");
        Serial.println(millis());

        Serial.println("[Main] Waiting 1s before BLE init...");
        delay(1000);
        Serial.print("[Main] Starting BLE at ms=");
        Serial.println(millis());
    }

    // Start BLE (if eligible). This call is safe when willRunBle is false (it will return early).
    coldStartBle.begin(wakeup_reason, reset_reason, skipBle);

    // Initialize app manager with core managers
    appManager.setWiFiManager(&wifiManager);
    appManager.setDisplayManager(&displayManager);
    appManager.setPowerManager(&powerManager);
    appManager.setOTAManager(&otaManager);
    
    // Register only the apps included in this build
#if defined(APP_FUN)
    appManager.registerApp(&funApp, "fun");
#endif
#if defined(APP_SENSOR)
    appManager.registerApp(&sensorApp, "sensor");
#endif
#if defined(APP_SHELF)
    appManager.registerApp(&shelfApp, "shelf");
#endif
#if defined(APP_MESSAGES)
    appManager.registerApp(&messagesApp, "messages");
#endif
#if !defined(APP_FUN) && !defined(APP_SENSOR) && !defined(APP_SHELF) && !defined(APP_MESSAGES)
    appManager.registerApp(&funApp, "fun");
    appManager.registerApp(&sensorApp, "sensor");
    appManager.registerApp(&shelfApp, "shelf");
    appManager.registerApp(&messagesApp, "messages");
#endif

    // Try to load configuration from Preferences (stored via BLE)
    String storedConfigJson = ColdStartBle::getStoredConfigJson();
    if (storedConfigJson.length() > 0) {
        Serial.println("[Main] Found stored configuration from BLE");
        Serial.print("[Main] Config JSON: ");
        Serial.println(storedConfigJson);
        
        // Parse and apply the stored config
        // The stored config format is: {"mode":"fun","timestamp":...,"refreshInterval":60,"apis":{...},"wifiSSID":"...","wifiPassword":"..."}
        // We need to convert it to app manager format: {"app":"fun","config":{...}}
        // For now, let's use ArduinoJson to transform it
        DynamicJsonDocument storedDoc(2048);
        DeserializationError error = deserializeJson(storedDoc, storedConfigJson);
        
        if (!error && storedDoc.containsKey("mode")) {
            // Create app manager format
            DynamicJsonDocument appDoc(2048);
            appDoc["app"] = storedDoc["mode"];
            
            // Copy config fields (refreshInterval, apis, sensor app fields, etc.) to config object
            JsonObject config = appDoc.createNestedObject("config");
            if (storedDoc.containsKey("refreshInterval")) {
                config["refreshInterval"] = storedDoc["refreshInterval"];
            }
            if (storedDoc.containsKey("apis")) {
                config["apis"] = storedDoc["apis"];
            }
            // Sensor app: temperature units (C/F), nemo token/url/sensor ID, location
            if (storedDoc.containsKey("units")) {
                config["units"] = storedDoc["units"];
            } else if (storedDoc.containsKey("temperatureUnit")) {
                config["units"] = storedDoc["temperatureUnit"];
            }
            if (storedDoc.containsKey("nemoToken")) {
                config["nemoToken"] = storedDoc["nemoToken"];
            } else if (storedDoc.containsKey("nemo_token")) {
                config["nemoToken"] = storedDoc["nemo_token"];
            }
            if (storedDoc.containsKey("nemoUrl")) {
                config["nemoUrl"] = storedDoc["nemoUrl"];
            } else if (storedDoc.containsKey("nemo_url")) {
                config["nemoUrl"] = storedDoc["nemo_url"];
            } else if (storedDoc.containsKey("nemoApiEndpoint")) {
                config["nemoUrl"] = storedDoc["nemoApiEndpoint"];
            }
            // Handle temperature and humidity sensor IDs separately
            if (storedDoc.containsKey("temperatureSensorId")) {
                config["temperatureSensorId"] = storedDoc["temperatureSensorId"];
            } else if (storedDoc.containsKey("temperature_sensor_id")) {
                config["temperatureSensorId"] = storedDoc["temperature_sensor_id"];
            }
            if (storedDoc.containsKey("humiditySensorId")) {
                config["humiditySensorId"] = storedDoc["humiditySensorId"];
            } else if (storedDoc.containsKey("humidity_sensor_id")) {
                config["humiditySensorId"] = storedDoc["humidity_sensor_id"];
            }
            if (storedDoc.containsKey("batterySensorId")) {
                config["batterySensorId"] = storedDoc["batterySensorId"];
            } else if (storedDoc.containsKey("battery_sensor_id")) {
                config["batterySensorId"] = storedDoc["battery_sensor_id"];
            }
            // Legacy support for single sensorId (for backwards compatibility)
            if (storedDoc.containsKey("sensorId") && !config.containsKey("temperatureSensorId")) {
                config["temperatureSensorId"] = storedDoc["sensorId"];
            } else if (storedDoc.containsKey("sensor_id") && !config.containsKey("temperatureSensorId")) {
                config["temperatureSensorId"] = storedDoc["sensor_id"];
            } else if (storedDoc.containsKey("nemoSensorId") && !config.containsKey("temperatureSensorId")) {
                config["temperatureSensorId"] = storedDoc["nemoSensorId"];
            }
            if (storedDoc.containsKey("sensorLocation")) {
                config["sensorLocation"] = storedDoc["sensorLocation"];
            } else if (storedDoc.containsKey("sensor_location")) {
                config["sensorLocation"] = storedDoc["sensor_location"];
            }
            if (storedDoc.containsKey("timeServer")) {
                config["timeServer"] = storedDoc["timeServer"];
            } else if (storedDoc.containsKey("time_server")) {
                config["timeServer"] = storedDoc["time_server"];
            }
            // Timezone selection for DST-aware local time (preferred)
            if (storedDoc.containsKey("timeZone")) {
                config["timeZone"] = storedDoc["timeZone"];
            } else if (storedDoc.containsKey("timezone")) {
                config["timeZone"] = storedDoc["timezone"];
            } else if (storedDoc.containsKey("time_zone")) {
                config["timeZone"] = storedDoc["time_zone"];
            }
            if (storedDoc.containsKey("gmtOffsetSec")) {
                config["gmtOffsetSec"] = storedDoc["gmtOffsetSec"];
            }
            if (storedDoc.containsKey("daylightOffsetSec")) {
                config["daylightOffsetSec"] = storedDoc["daylightOffsetSec"];
            }
            // Shelf app: bin ID, server host, server port
            if (storedDoc.containsKey("binId")) {
                config["binId"] = storedDoc["binId"];
            } else if (storedDoc.containsKey("bin_id")) {
                config["binId"] = storedDoc["bin_id"];
            }
            if (storedDoc.containsKey("serverHost")) {
                config["serverHost"] = storedDoc["serverHost"];
            } else if (storedDoc.containsKey("server_host")) {
                config["serverHost"] = storedDoc["server_host"];
            }
            if (storedDoc.containsKey("serverPort")) {
                config["serverPort"] = storedDoc["serverPort"];
            } else if (storedDoc.containsKey("server_port")) {
                config["serverPort"] = storedDoc["server_port"];
            }
            // Device identity (friendly name + optional phone-mint UUID) for fun aggregator / messaging
            if (storedDoc.containsKey("displayName")) {
                config["displayName"] = storedDoc["displayName"];
            } else if (storedDoc.containsKey("deviceFriendlyName")) {
                config["displayName"] = storedDoc["deviceFriendlyName"];
            } else if (storedDoc.containsKey("friendly_name")) {
                config["displayName"] = storedDoc["friendly_name"];
            }
            if (storedDoc.containsKey("deviceId")) {
                config["deviceId"] = storedDoc["deviceId"];
            } else if (storedDoc.containsKey("device_id")) {
                config["deviceId"] = storedDoc["device_id"];
            }
            // Messages app: array of up to 10 messages
            if (storedDoc.containsKey("messages") && storedDoc["messages"].is<JsonArray>()) {
                config["messages"] = storedDoc["messages"];
            } else {
                bool hasMessage = false;
                JsonArray msgArr;
                for (int i = 1; i <= 10; i++) {
                    String key = "message" + String(i);
                    if (storedDoc.containsKey(key.c_str())) {
                        if (!hasMessage) {
                            msgArr = config.createNestedArray("messages");
                            hasMessage = true;
                        }
                        msgArr.add(storedDoc[key.c_str()]);
                    }
                }
            }
            // Legacy support: if serverUrl is provided, try to parse it
            if (storedDoc.containsKey("serverUrl") || storedDoc.containsKey("server_url")) {
                String serverUrl = storedDoc.containsKey("serverUrl") 
                    ? storedDoc["serverUrl"].as<const char*>()
                    : storedDoc["server_url"].as<const char*>();
                // Try to parse URL format: http://host:port or host:port
                int protocolEnd = serverUrl.indexOf("://");
                String hostPort = (protocolEnd >= 0) ? serverUrl.substring(protocolEnd + 3) : serverUrl;
                int colonPos = hostPort.indexOf(':');
                if (colonPos > 0) {
                    config["serverHost"] = hostPort.substring(0, colonPos);
                    config["serverPort"] = hostPort.substring(colonPos + 1).toInt();
                } else {
                    config["serverHost"] = hostPort;
                }
            }
            
            String appConfigJson;
            serializeJson(appDoc, appConfigJson);
            
            Serial.print("[Main] Transformed config: ");
            Serial.println(appConfigJson);
            
            // Try to configure with the stored config
            // If the app doesn't exist, silently fall back to default (this is loading from NVS, not receiving via BLE)
            if (appManager.configureFromJson(appConfigJson.c_str())) {
                Serial.println("[Main] Stored configuration loaded successfully");
            } else {
                // Requested app not in firmware - silently fall back to default
                Serial.print("[Main] Requested app not in firmware, using default app: ");
                Serial.println(DEFAULT_APP_NAME);
                appManager.setActiveApp(DEFAULT_APP_NAME);
            }
        } else {
            Serial.println("[Main] Failed to parse stored config, using default");
            appManager.setActiveApp(DEFAULT_APP_NAME);
        }
    } else {
        Serial.println("[Main] No stored configuration found, using test config");
        // Configure from JSON (for testing)
        if (appManager.configureFromJson(TEST_CONFIG_JSON)) {
            Serial.println("[Main] Test configuration loaded successfully");
        } else {
            Serial.println("[Main] Configuration failed, using default");
            appManager.setActiveApp(DEFAULT_APP_NAME);
        }
    }
    
    // Begin the active app
    appManager.begin();

    Serial.print("[Main] setup() complete in ms=");
    Serial.println((uint32_t)(millis() - bootStartMs));
    Serial.println("==========================");
}

void loop() {
    // Cold-start BLE: disable after window timeout or first connection
    coldStartBle.loop();

    // Check battery level before running app
    int batteryPercent = powerManager.getBatteryPercentage();
    if (batteryPercent <= BATTERY_LOW_THRESHOLD_PERCENT) {
        Serial.println("[Main] Battery critically low during operation, showing message and entering low battery sleep");
        displayManager.begin();
        displayManager.displayLowBatteryMessage();
        delay(2000); // Give time for message to be visible
        powerManager.enterLowBatterySleep();
        // Code never reaches here
        return;
    }

    // While BLE config mode is active, keep showing the config screen (don't run app loop).
    // After BLE times out or config is received, run the app and it will update the display.
    if (!coldStartBle.isActive()) {
        appManager.loop();
    }

    // Note: Individual apps handle their own sleep/wake cycles
    // The app manager just coordinates which app is running
}

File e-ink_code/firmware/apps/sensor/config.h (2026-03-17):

#ifndef SENSOR_APP_CONFIG_H
#define SENSOR_APP_CONFIG_H

#include "../../core/hardware_config.h"

// SHT31 I2C address (default)
#define SHT31_I2C_ADDR 0x44

// Default Nemo API endpoint
#define SENSOR_APP_DEFAULT_NEMO_URL "https://nemo.stanford.edu/api/sensors/sensor_data/"

// Default NTP time server (UTC) and timezone rules (DST handled locally via TZ rule)
#define SENSOR_APP_DEFAULT_TIME_SERVER "pool.ntp.org"
// When using TZ rules, keep NTP sync in UTC (offsets 0); localtime() uses TZ rules for DST.
#define SENSOR_APP_DEFAULT_GMT_OFFSET_SEC  0
#define SENSOR_APP_DEFAULT_DAYLIGHT_OFFSET_SEC 0

// Timezone selection values expected from configuration UI
#define SENSOR_APP_TIMEZONE_PACIFIC   "pacific"
#define SENSOR_APP_TIMEZONE_MOUNTAIN  "mountain"
#define SENSOR_APP_TIMEZONE_CENTRAL   "central"
#define SENSOR_APP_TIMEZONE_EASTERN   "eastern"
#define SENSOR_APP_TIMEZONE_ARIZONA   "arizona"
#define SENSOR_APP_TIMEZONE_UTC       "utc"

// POSIX TZ rule strings (US DST rules where applicable)
#define SENSOR_APP_TZ_RULE_PACIFIC   "PST8PDT,M3.2.0/2,M11.1.0/2"
#define SENSOR_APP_TZ_RULE_MOUNTAIN  "MST7MDT,M3.2.0/2,M11.1.0/2"
#define SENSOR_APP_TZ_RULE_CENTRAL   "CST6CDT,M3.2.0/2,M11.1.0/2"
#define SENSOR_APP_TZ_RULE_EASTERN   "EST5EDT,M3.2.0/2,M11.1.0/2"
#define SENSOR_APP_TZ_RULE_ARIZONA   "MST7"
#define SENSOR_APP_TZ_RULE_UTC       "UTC0"

#define SENSOR_APP_DEFAULT_TIMEZONE SENSOR_APP_TIMEZONE_PACIFIC
#define SENSOR_APP_DEFAULT_TZ_RULE SENSOR_APP_TZ_RULE_PACIFIC

#endif // SENSOR_APP_CONFIG_H

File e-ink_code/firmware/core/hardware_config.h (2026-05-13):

#ifndef HARDWARE_CONFIG_H
#define HARDWARE_CONFIG_H

// ============================================================================
// Pin Definitions for ESP32-C3
// ============================================================================


#define SPI_MISO  -1


#define I2C_SDA   9
#define I2C_SCL   10
#define V_ADC     2
// Pin 20: enables voltage divider for battery measurement (LOW = on; power_manager drives it during read)
#define V_SWITCH  20

// Pin 8: MOSFET gate for power to temperature sensor and display (LOW = power on)
#define POWER_DISPLAY_SENSOR_PIN 8

#define BUSY_PIN  21
#define CS_PIN    7
#define DC_PIN    6
#define RST_PIN   5
#define SPI_MOSI  4
#define SPI_SCK   3

// ============================================================================
// Power Management Constants
// ============================================================================
// Voltage divider resistor values (ohms)
#define BATTERY_R1           47000
#define BATTERY_R2           68000

// Battery voltage range for percentage calculation
#define BATTERY_HIGH_VOLTAGE 4.15f
#define BATTERY_LOW_VOLTAGE  2.8f

// Set to 1 to use delay() instead of deep sleep (keeps Serial and USB alive for testing)
#define DISABLE_DEEP_SLEEP_FOR_TESTING 0

// Battery management thresholds
#define BATTERY_LOW_THRESHOLD_PERCENT  5   // Enter low battery sleep mode at this level
#define BATTERY_RESUME_THRESHOLD_PERCENT 15  // Resume normal operation when battery reaches this level
#define LOW_BATTERY_WAKEUP_INTERVAL_SECONDS 300  // Wake up every 5 minutes to check battery when in low battery mode

// ============================================================================
// Network Configuration
// ============================================================================
// WiFi credentials are now configured via BLE and stored in Preferences
// Use ColdStartBle::getStoredWiFiSSID() and ColdStartBle::getStoredWiFiPassword()
// to retrieve them at runtime.

// OTA Update Server Configuration
#define OTA_VERSION_CHECK_URL "https://your-server.com/api/version"
#define OTA_PASSWORD          "your-secure-password-here"
#define FIRMWARE_VERSION      "1.0.0"

// Root CA Certificate (paste your server's root CA cert here)
#define ROOT_CA_CERT \
"-----BEGIN CERTIFICATE-----\n" \
"YOUR_ROOT_CA_CERTIFICATE_HERE\n" \
"-----END CERTIFICATE-----\n"

// Fun aggregator (Raspberry Pi). Use http://host:8080 for LAN HTTP or https:// with valid CA in ROOT_CA_CERT.
#define FUN_FACTS_BASE_URL "http://192.168.1.10:8080"
// Optional: must match server FUN_API_KEY if set; leave empty for open LAN
#define FUN_FACTS_API_KEY ""

#endif // HARDWARE_CONFIG_H

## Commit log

2026-01-24 working battery voltage
2026-01-24 fine tuning battery voltage
2026-01-25 adding KiCAD
    [e-ink_PCB.kicad_pcb, e-ink_PCB.kicad_sch]
2026-01-25 kiCAD correct display orientation
    [e-ink_PCB.kicad_pcb, e-ink_PCB.kicad_sch]
2026-01-26 kiCAD shipped
    [e-ink_PCB-B_Cu.gbr, e-ink_PCB-B_Mask.gbr, e-ink_PCB-Edge_Cuts.gbr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]
2026-01-26 seperated files by functionality, added flash partitioning
    [partitions.csv]
2026-01-28 throughole design
    [e-ink_PCB-B_Cu.gbr, e-ink_PCB-B_Mask.gbr, e-ink_PCB-B_Paste.gbr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]
2026-02-03 seperated compiling
    [partitions.csv]
2026-02-04 BLE working, including reboot
    [app.cpp, cold_start_ble.cpp, hardware_config.h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]
2026-02-04 Pretty close on the sensor
2026-02-05 accepts multiple sensor fields
2026-02-06 added battery low message
2026-02-11 updates to KiCAD
    [e-ink_PCB.kicad_pcb, e-ink_PCB.kicad_sch]
2026-03-02 sensor firmware now pushes to nemo
2026-03-09 folder re-org, MOSFET design
    [e-ink_PCB-B_Cu.gbr, e-ink_PCB-B_Mask.gbr, e-ink_PCB-B_Paste.gbr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]
2026-03-09 almost final throughole-basic
    [e-ink_PCB.kicad_pcb]
2026-03-17 added time, new PCB design
2026-03-24 changes to sensor code
    [e-ink_PCB-B_Cu.gbr, e-ink_PCB-B_Mask.gbr, e-ink_PCB-B_Paste.gbr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]
2026-05-09 almost OSHWA ready
    [E-ink BOMs - Basic.csv, bom-SMD.csv, bom-Throughole-RTC.csv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]
